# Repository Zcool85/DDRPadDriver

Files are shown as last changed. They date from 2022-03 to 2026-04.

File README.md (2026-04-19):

# Introduction

Projet de création d'un tapis de dance pour le jeu Dance Dance Revolution.

Ce tapis est utilisable sur un PC pour des jeux comme `Stepmania` ou `Outfox`, mais également sur
console Playstation (1 et 2).

Le firmware est à base de microcontroller AVR ©.

Les touches du tapis peuvent être illuminées. Dans ce cas, il convient d'ajouter une alimentation externe pour les LED (CAO `Power_Supply`). Cette alimentation est inutile si le tapis est utilisé sans éclairage.

## Licence

Le présent projet est sous licence MIT (Cf. [License](LICENSE.md)).

ATTENTION : Le Firmware utilise une librairie tierce V-USB pour la connexion USB vers un PC.
Cette librairie est soumie à une licnece GNU General Public License Version 2 (GPL). Merci
de consulter a license de cette bibliothèque en cas de modification.

Cf. [Librairie V-USB](https://obdev.at/products/vusb/index.html).

## Organisation du repo

Le répertoire `CAD` contient les fichiers de CAO des diférents composants :
- `Power_Supply` : Fichier CAO utilisé pour le bloc d'alimentation des tapis
- `For_Childrens` : Fichier CAO utilisé pour créer un tapis à la taille d'un enfant (~6ans)
- `For_Adults` : Fichier CAO utilisé pour créer un tapis pour adulte
- `Fonts` : Répertoire contenant les fonts utilisées par les fichiers de CAO

Le répertoire `Schematics` contient le shéma du circuit électronique du tapis.

Le répertoire `Datasheets` contient tous les datasheets des composants utilisés par le circuit électronique.

Le répertoire `Firmware` contient le code complet du firmware du microcontroller présent dans le circtui électronique.

Le répertoire `Documentation` Contient un peu de documentation permettant de comprendre comment fonctionne les trames d'une manette PS2.

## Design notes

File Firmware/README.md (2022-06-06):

# Introduction

Firmware pour un microcontoller AVR © permettant de gérer un tapis de dance DDR.

Ce firmware permet de se branche en USB sur un PC, ou sur une console Playstation.

## Trucs et astuces

### Installation des toolkit AVR GCC

Cf. [Doc](https://github.com/osx-cross/homebrew-avr)

```sh
brew tap osx-cross/avr
brew install avr-gcc
```

### Programmer les fuses

Commande à lancer (via ll'usage d'un AVR ISP mk II) :

```sh
avrdude -C avrdude.conf -p m324p -P usb -c avrispmkII -U efuse:w:efuse.bin:r -U hfuse:w:hfuse.bin:r -U lfuse:w:lfuse.bin:r
avrdude -C avrdude.conf -p m324p -P usb -c stk600pp   -U efuse:w:efuse.bin:r -U hfuse:w:hfuse.bin:r -U lfuse:w:lfuse.bin:r
```

### Faire une réinitialisation d'un AVR via Parallel High-Voltage Programming

Le présent process est fonctionnel pour une carte de développement STK600.

Cf. [Documentation](http://ww1.microchip.com/downloads/en/devicedoc/40001904a.pdf)

#### Pour un ATtiny48-PU

Use STK600-RC028M-6 PCB
Use STK600-DIP PCB

Connect PROGCTRL cable
Connect PROGDATA cable

Mount VTARGET jumper
Mount RESET jumper

avrdude -C avrdude.conf -c stk600pp -p attiny48 -P usb -U lfuse:w:lfuse.bin:r -U hfuse:w:hfuse.bin:r -U efuse:w:efuse.bin:r

#### Pour un ATMega324p-20PU

Use STK600-RC040M-5 PCB
Use STK600-DIP PCB

Connect PROGCTRL cable
Connect PROGDATA cable

Mount VTARGET jumper
Mount RESET jumper

avrdude -C avrdude.conf -c stk600pp -p m324p -P usb -U lfuse:w:lfuse.bin:r -U hfuse:w:hfuse.bin:r -U efuse:w:efuse.bin:r

### Visualiser les données USART sous MacOS

```sh
sudo cu -s 115200 -l /dev/tty.usbserial-A9IM6MKT
```

NOTE : `~.` pour terminer la communication.

### Visualiser la liste des périphérique USB sur MacOS

```sh
ioreg -p IOUSB
```

### Tester un joystick sous Windows

```cmd
joy.cpl
```

Note sur les [pilotes Windows](https://www.raphnet-tech.com/support/testing/index_fr.php).

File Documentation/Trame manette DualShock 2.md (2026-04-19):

# Trame Duacl Shock 2 sur PS2

Passage du mode digital à analogique (via la manette)

```
0x01/0xFF 0x42/0x41 0x00/0x5A 0x00/0xFF 0x00/0xFF
0x01/0xFF 0x42/0x41 0x00/0x5A 0x00/0xFF 0x00/0xFF
0x01/0xFF 0x42/0x41 0x00/0x5A 0x00/0xFF 0x00/0xFF
0x01/0xFF 0x42/0x41 0x00/0x5A 0x00/0xFF 0x00/0xFF
0x01/0xFF 0x42/0x41 0x00/0x5A 0x00/0xFF 0x00/0xFF
0x01/0xFF 0x42/0x41 0x00/0x5A 0x00/0xFF 0x00/0xFF
0x01/0xFF 0x42/0x41 0x00/0x5A 0x00/0xFF 0x00/0xFF
0x01/0xFF 0x42/0x41 0x00/0x5A 0x00/0xFF 0x00/0xFF
0x01/0xFF 0x42/0x41 0x00/0x5A 0x00/0xFF 0x00/0xFF
0x01/0xFF 0x42/0x41 0x00/0x5A 0x00/0xFF 0x00/0xFF
0x01/0xFF 0x42/0x41 0x00/0x5A 0x00/0xFF 0x00/0xFF
0x01/0xFF 0x42/0x41 0x00/0x5A 0x00/0xFF 0x00/0xFF
0x01/0xFF 0x42/0x41 0x00/0x5A 0x00/0xFF 0x00/0xFF
0x01/0xFF 0x42/0x73 0x00/0x00 0x00/0xFF 0x00/0xFF
0x01/0xFF 0x42/0x73 0x00/0x00 0x00/0xFF 0x00/0xFF
0x01/0xFF 0x43/0x73 0x00/0x00 0x01/0xFF 0x00/0xFF 0x00/0x79 0x00/0x89 0x00/0x75 0x00/0x71
0x01/0xFF 0x45/0xF3 0x00/0x5A 0x5A/0x03 0x5A/0x02 0x5A/0x01 0x5A/0x02 0x5A/0x01 0x5A/0x00
0x01/0xFF 0x46/0xF3 0x00/0x5A 0x00/0x00 0x5A/0x00 0x5A/0x01 0x5A/0x02 0x5A/0x00 0x5A/0x0A
0x01/0xFF 0x46/0xF3 0x00/0x5A 0x01/0x00 0x5A/0x00 0x5A/0x01 0x5A/0x01 0x5A/0x01 0x5A/0x14
0x01/0xFF 0x47/0xF3 0x00/0x5A 0x00/0x00 0x5A/0x00 0x5A/0x02 0x5A/0x00 0x5A/0x01 0x5A/0x00
0x01/0xFF 0x4C/0xF3 0x00/0x5A 0x00/0x00 0x5A/0x00 0x5A/0x00 0x5A/0x04 0x5A/0x00 0x5A/0x00
0x01/0xFF 0x4C/0xF3 0x00/0x5A 0x01/0x00 0x5A/0x00 0x5A/0x00 0x5A/0x07 0x5A/0x00 0x5A/0x00
0x01/0xFF 0x4D/0xF3 0x00/0x5A 0xFF/0xFF 0xFF/0xFF 0xFF/0xFF 0xFF/0xFF 0xFF/0xFF 0xFF/0xFF
0x01/0xFF 0x41/0xF3 0x00/0x5A 0x5A/0xFF 0x5A/0xFF 0x5A/0x03 0x5A/0x00 0x5A/0x00 0x5A/0x5A
0x01/0xFF 0x43/0xF3 0x00/0x5A 0x00/0x00 0x5A/0x00 0x5A/0x00 0x5A/0x00 0x5A/0x00 0x5A/0x00
0x01/0xFF 0x42/0x73 0x00/0x5A 0x00/0xFF 0x00/0xFF
0x01/0xFF 0x42/0x73 0x00/0x5A 0x00/0xFF 0x00/0xFF 0x00/0x79 0x00/0x89 0x00/0x75 0x00/0x71
0x01/0xFF 0x42/0x73 0x00/0x5A 0x00/0xFF 0x00/0xFF 0x00/0x79 0x00/0x89 0x00/0x75 0x00/0x71
0x01/0xFF 0x42/0x73 0x00/0x5A 0x00/0xFF 0x00/0xFF 0x00/0x79 0x00/0x89 0x00/0x75 0x00/0x71
0x01/0xFF 0x42/0x73 0x00/0x5A 0x00/0xFF 0x00/0xFF 0x00/0x79 0x00/0x89 0x00/0x75 0x00/0x71
0x01/0xFF 0x42/0x73 0x00/0x5A 0x00/0xFF 0x00/0xFF 0x00/0x79 0x00/0x89 0x00/0x75 0x00/0x71
0x01/0xFF 0x42/0x73 0x00/0x5A 0x00/0xFF 0x00/0xFF 0x00/0x79 0x00/0x89 0x00/0x75 0x00/0x71
0x01/0xFF 0x42/0x73 0x00/0x5A 0x00/0xFF 0x00/0xFF 0x00/0x79 0x00/0x89 0x00/0x75 0x00/0x71
0x01/0xFF 0x42/0x73 0x00/0x5A 0x00/0xFF 0x00/0xFF 0x00/0x79 0x00/0x89 0x00/0x75 0x00/0x71
0x01/0xFF 0x42/0x73 0x00/0x5A 0x00/0xFF 0x00/0xFF 0x00/0x79 0x00/0x89 0x00/0x75 0x00/0x71
0x01/0xFF 0x42/0x73 0x00/0x5A 0x00/0xFF 0x00/0xFF 0x00/0x79 0x00/0x89 0x00/0x75 0x00/0x71
0x01/0xFF 0x42/0x73 0x00/0x5A 0x00/0xFF 0x00/0xFF 0x00/0x79 0x00/0x89 0x00/0x75 0x00/0x71
0x01/0xFF 0x42/0x73 0x00/0x5A 0x00/0xFF 0x00/0xFF 0x00/0x79 0x00/0x89 0x00/0x75 0x00/0x71
0x01/0xFF 0x42/0x73 0x00/0x5A 0x00/0xFF 0x00/0xFF 0x00/0x79 0x00/0x89 0x00/0x75 0x00/0x71
0x01/0xFF 0x42/0x73 0x00/0x5A 0x00/0xFF 0x00/0xFF 0x00/0x79 0x00/0x89 0x00/0x75 0x00/0x71
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
```

NOTE : Une trame complète toutes les 20ms environ.

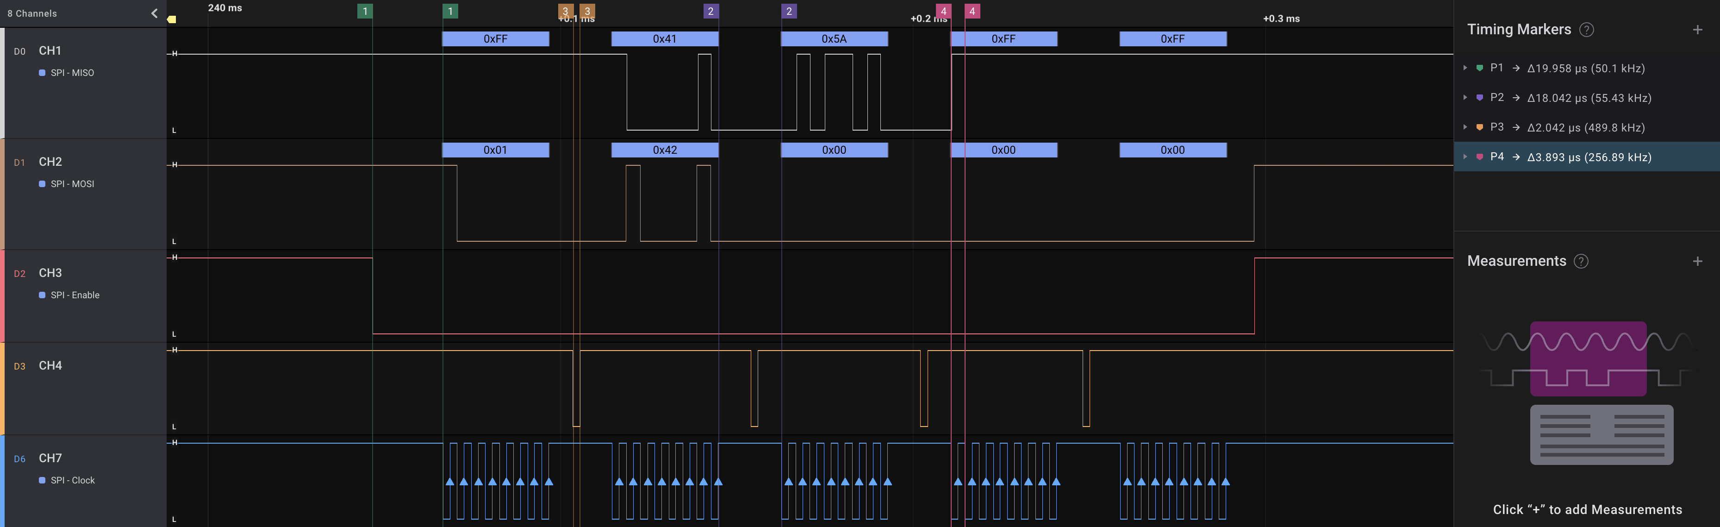
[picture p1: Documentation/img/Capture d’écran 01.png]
Trame 1

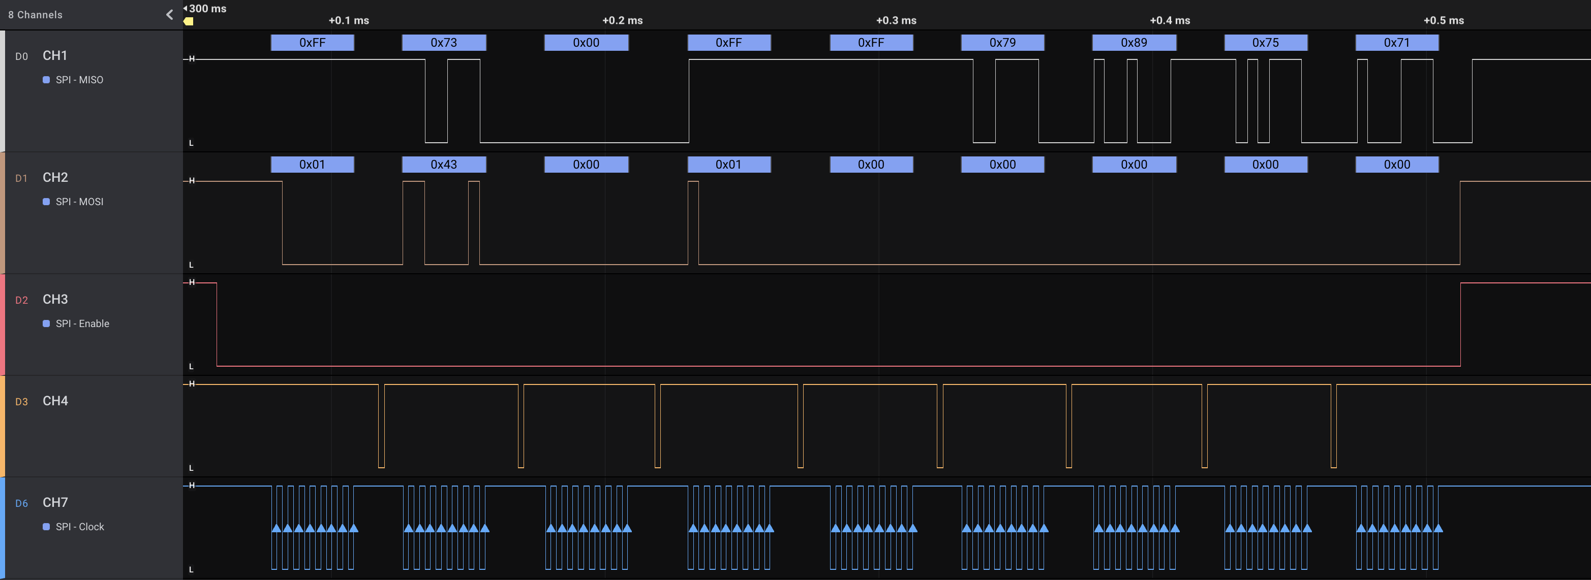
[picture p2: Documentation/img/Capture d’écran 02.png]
Trame 2

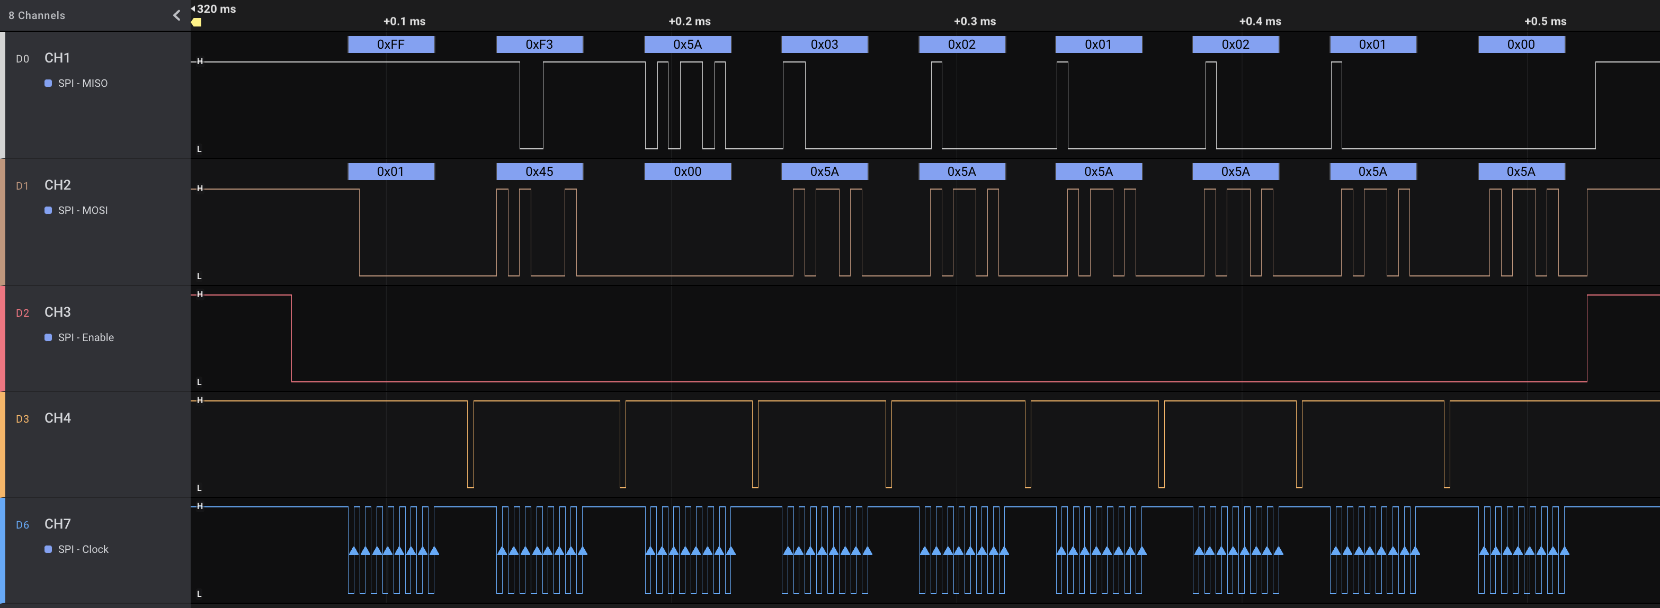
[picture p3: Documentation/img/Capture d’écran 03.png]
Trame 3

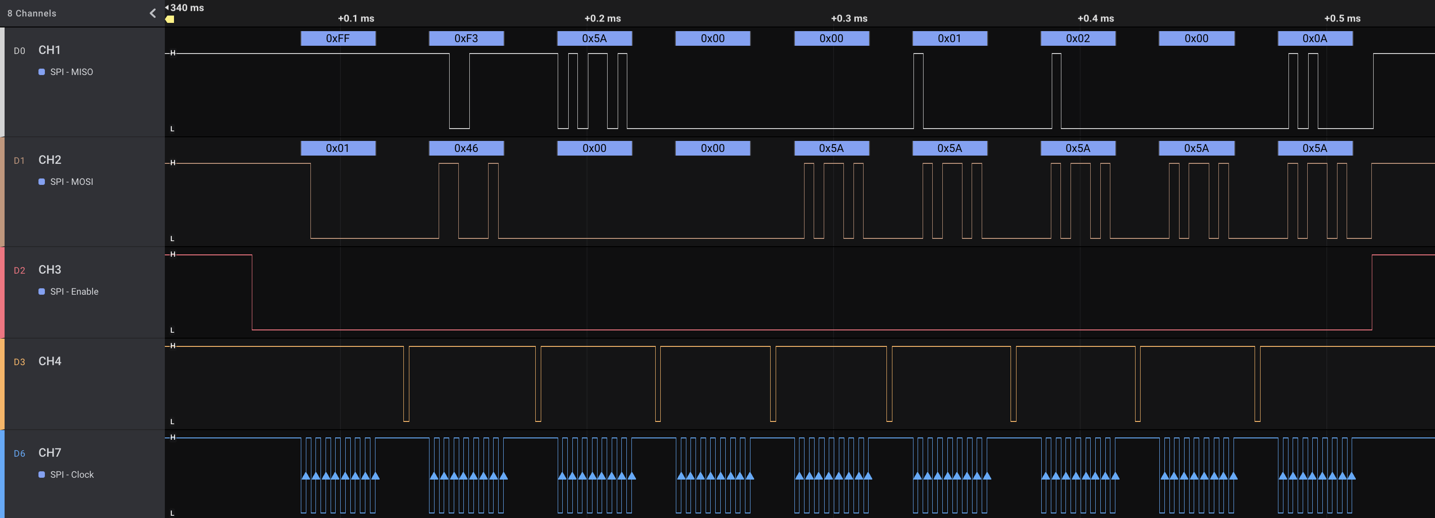
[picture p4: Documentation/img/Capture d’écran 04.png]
Trame 4

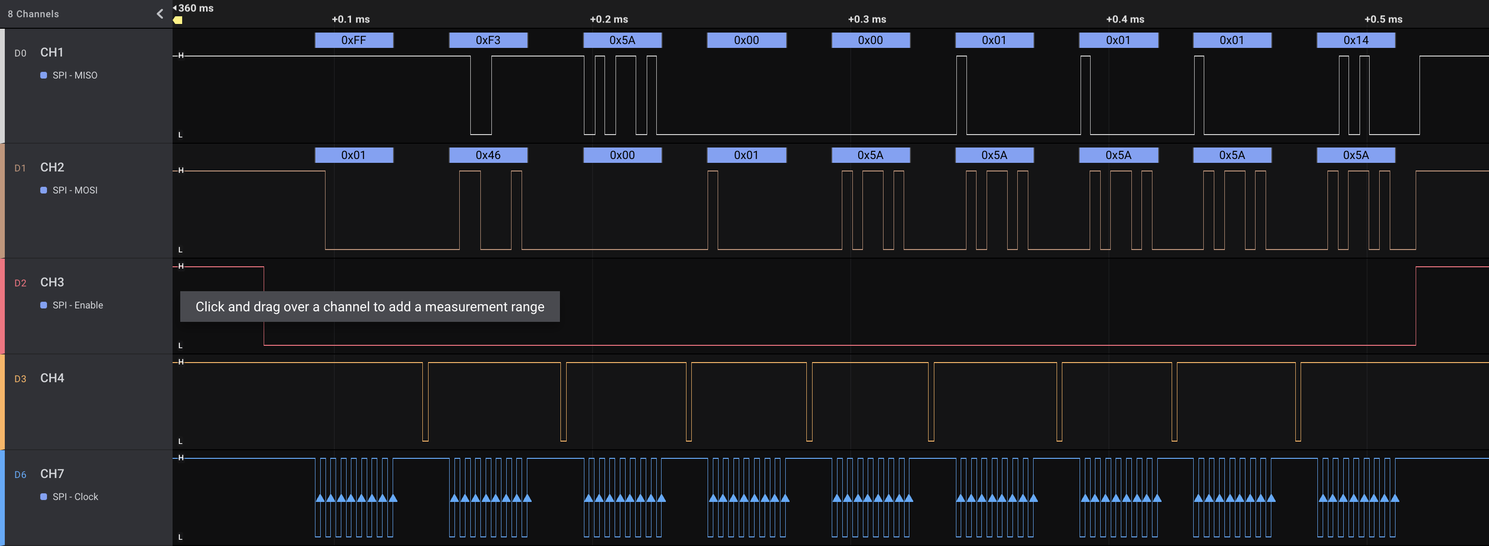
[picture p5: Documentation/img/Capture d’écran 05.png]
Trame 5

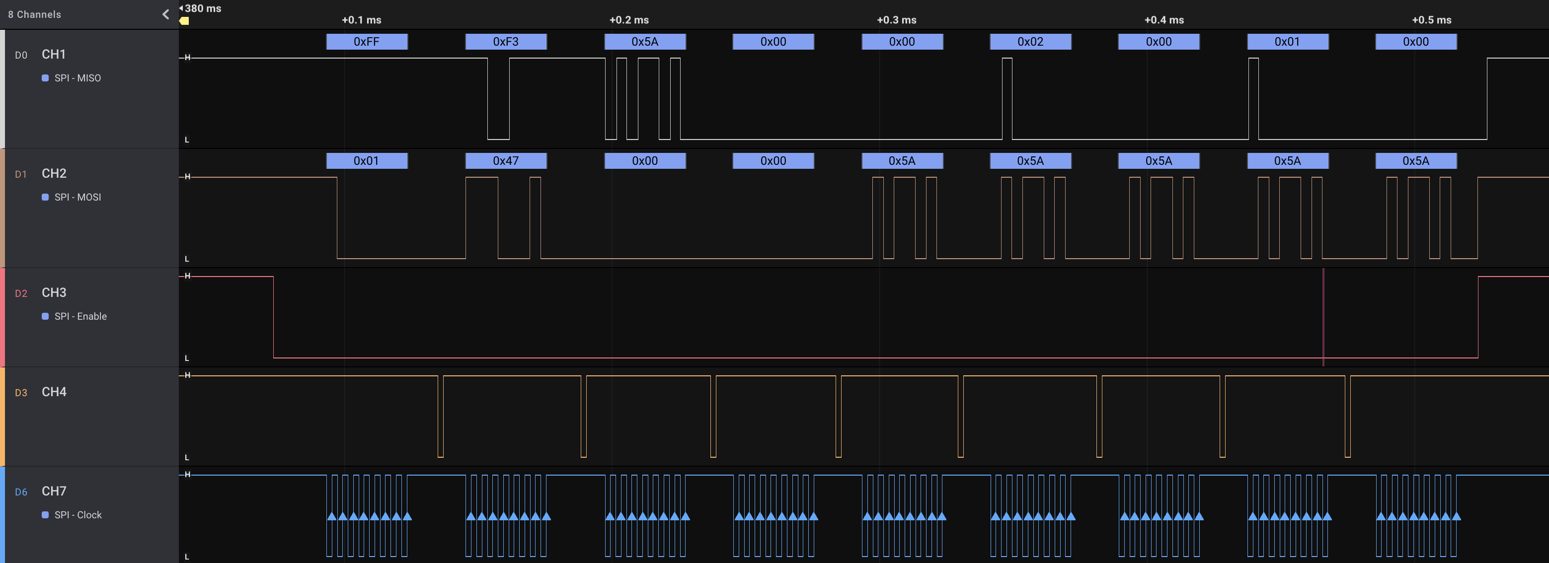
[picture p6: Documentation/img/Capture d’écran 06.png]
Trame 6

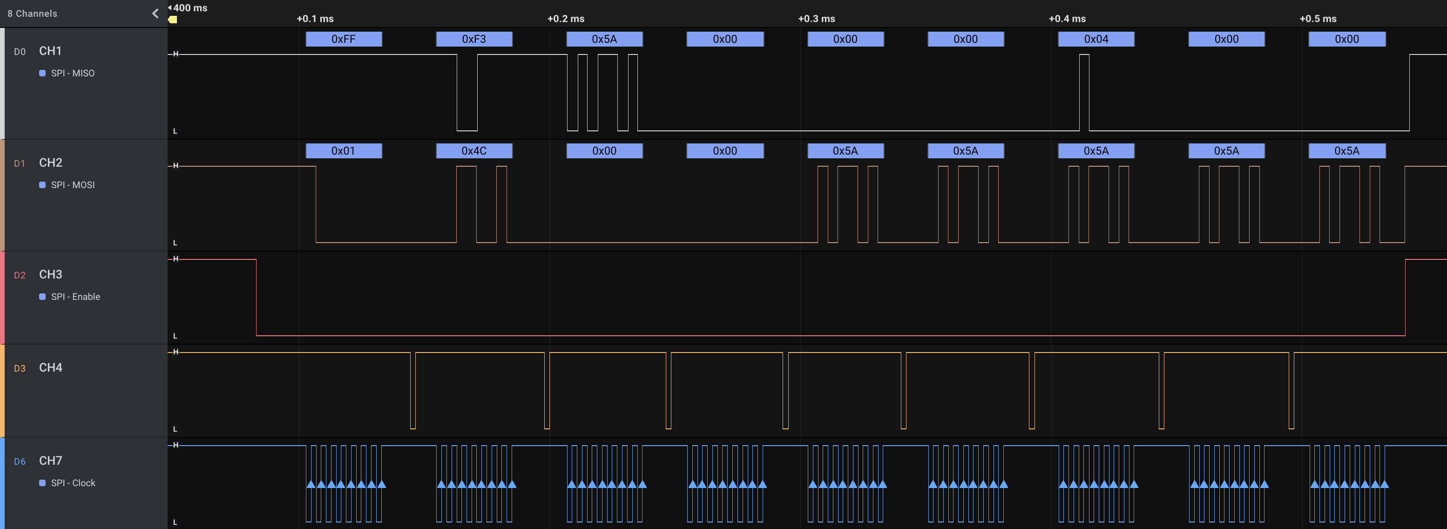
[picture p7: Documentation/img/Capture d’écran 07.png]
Trame 7

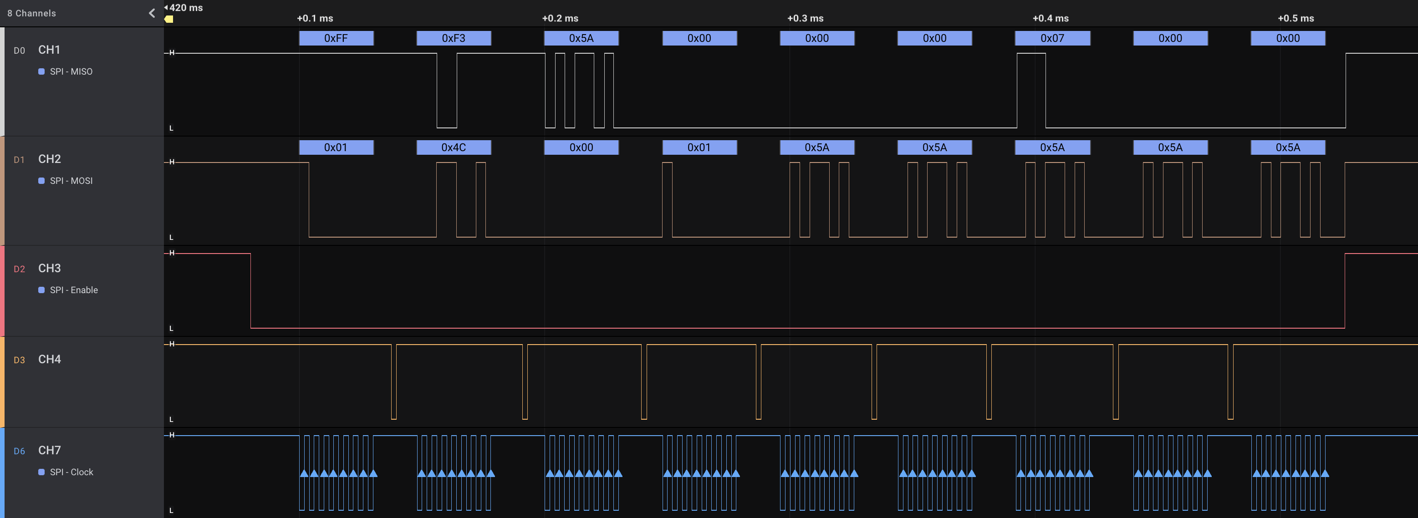
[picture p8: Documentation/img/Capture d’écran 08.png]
Trame 8

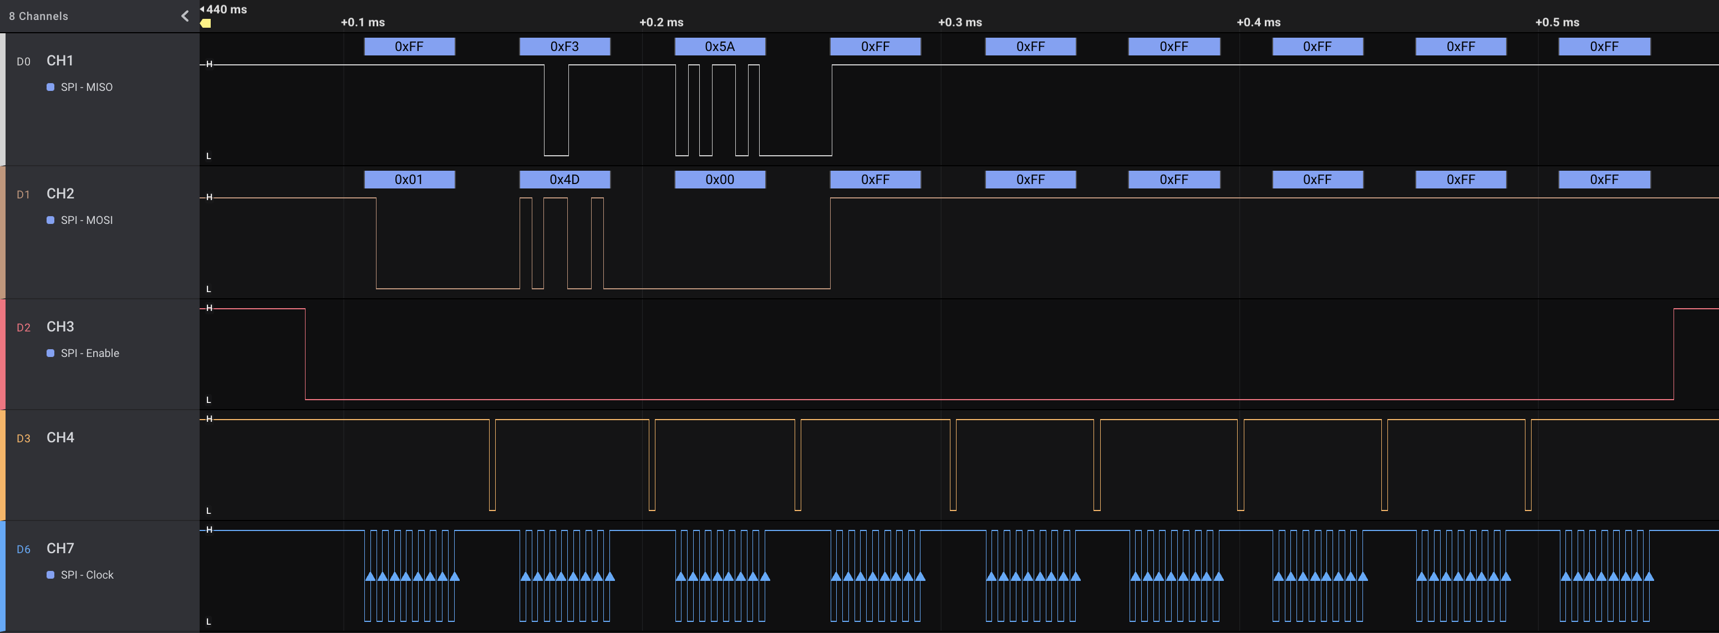
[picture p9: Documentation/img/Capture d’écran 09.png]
Trame 9

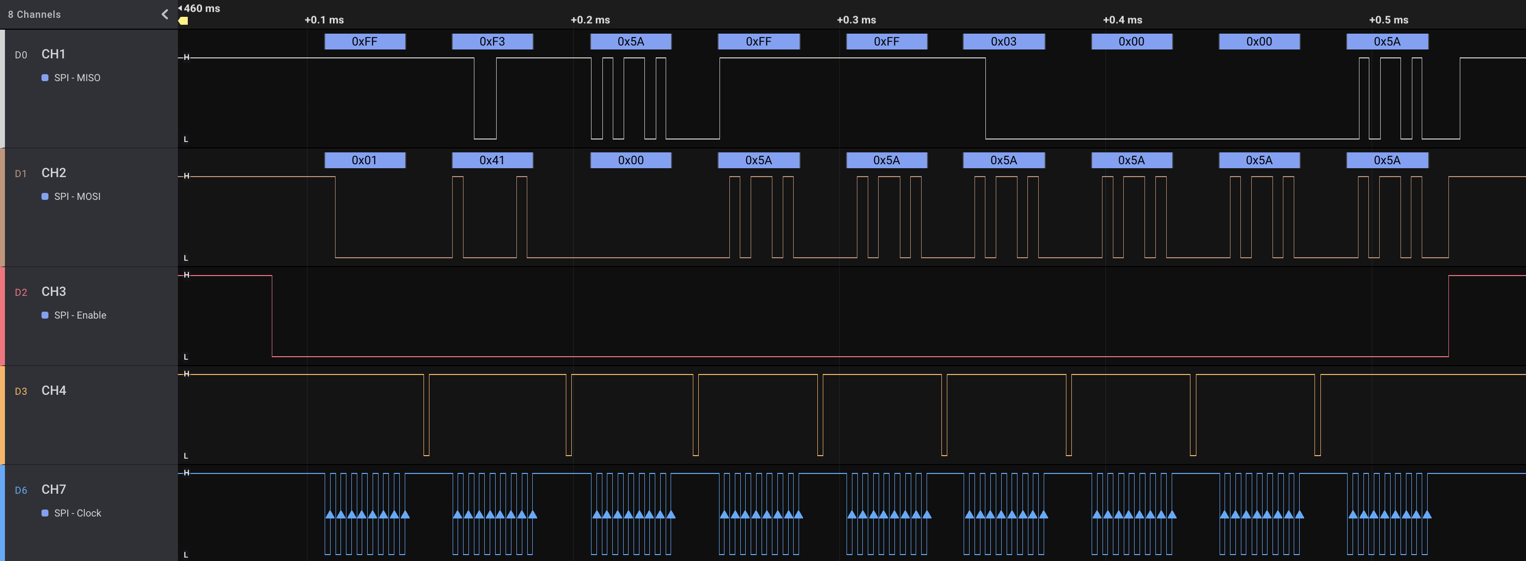
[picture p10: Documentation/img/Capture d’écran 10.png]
Trame 10

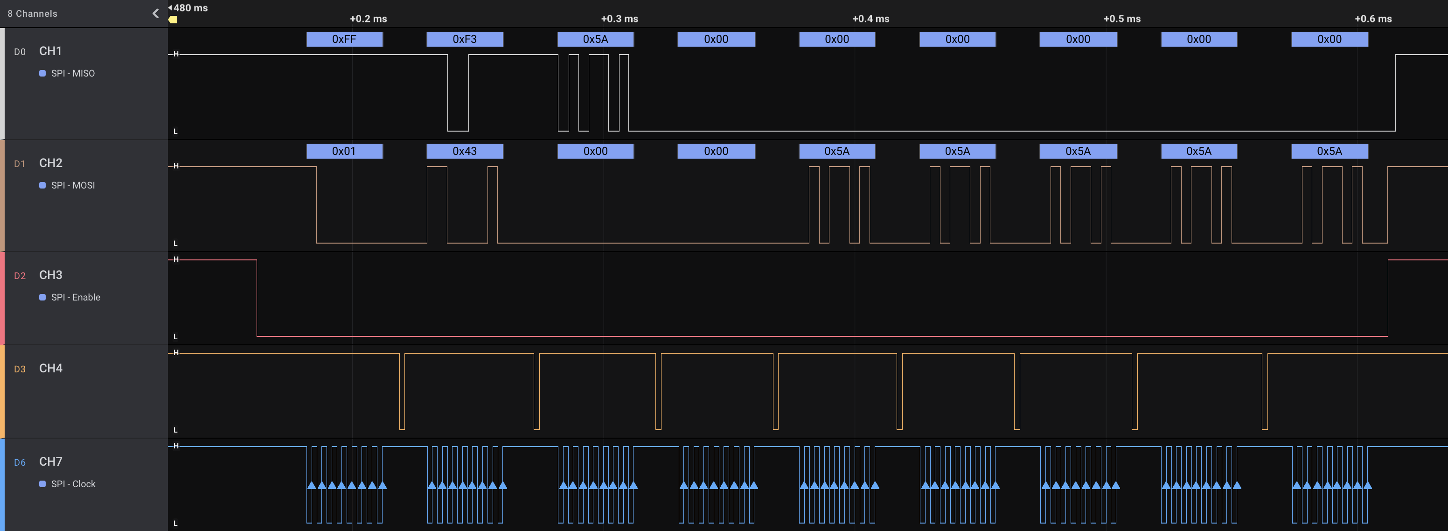
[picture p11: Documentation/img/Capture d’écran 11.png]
Trame 11

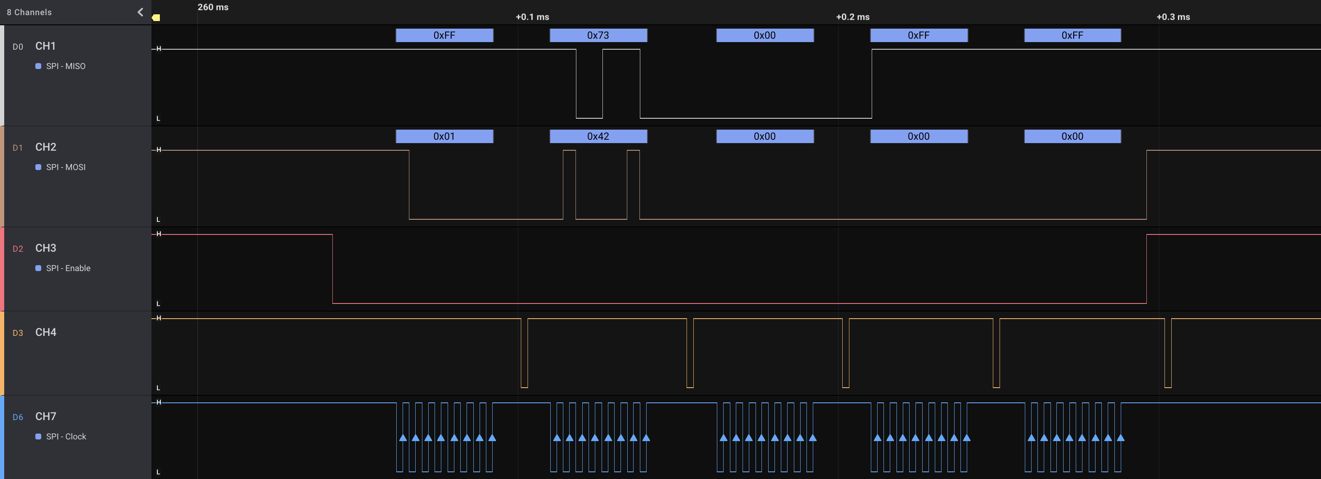
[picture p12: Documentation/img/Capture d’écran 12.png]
Trame 12

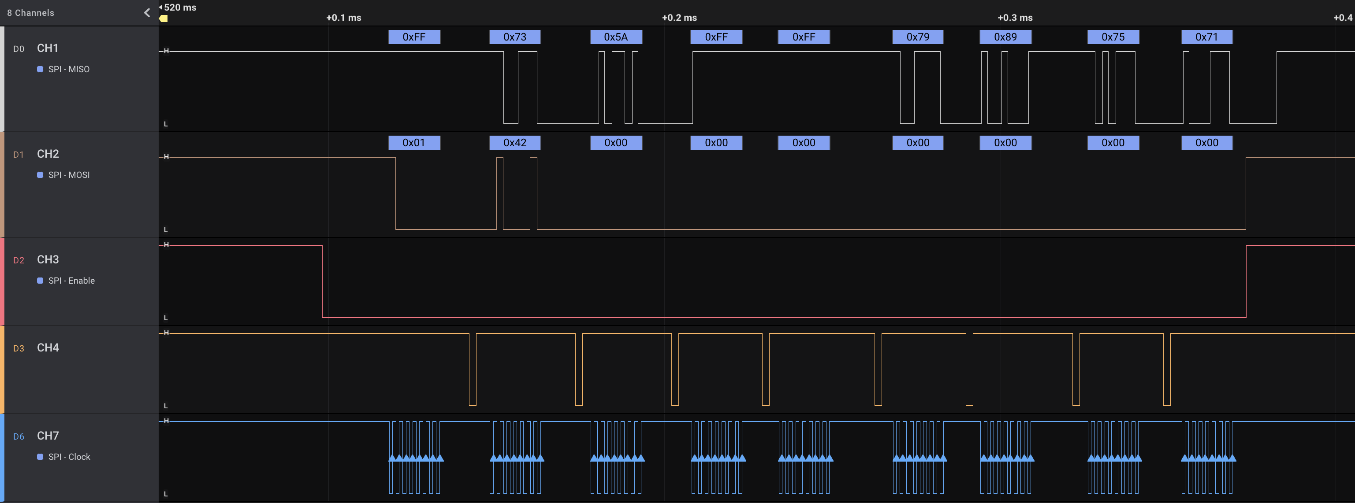
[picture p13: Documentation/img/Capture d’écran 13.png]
Trame 13


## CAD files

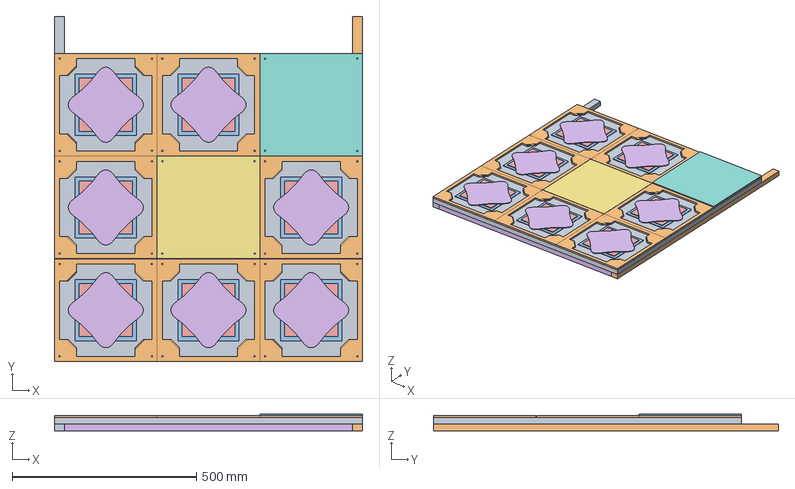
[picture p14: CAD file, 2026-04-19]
CAD/For_Adults/DancePad.FCStd
835.0 x 935.0 x 45.0 mm
Border_Body x 8
ContactBottom_Body x 16
ContactIsolation_Body x 8
FirstPadding_Body x 8
SecondPadding_Body x 8
VerticalSupport_Right_Body
VerticalSupport_Left_Body
HorizontalCrossing_Left_Body
HorizontalCrossing_Right_Body
HorizontalSupport_Up_Body
HorizontalSupport_Bottom_Body
VerticalCrossing_Body

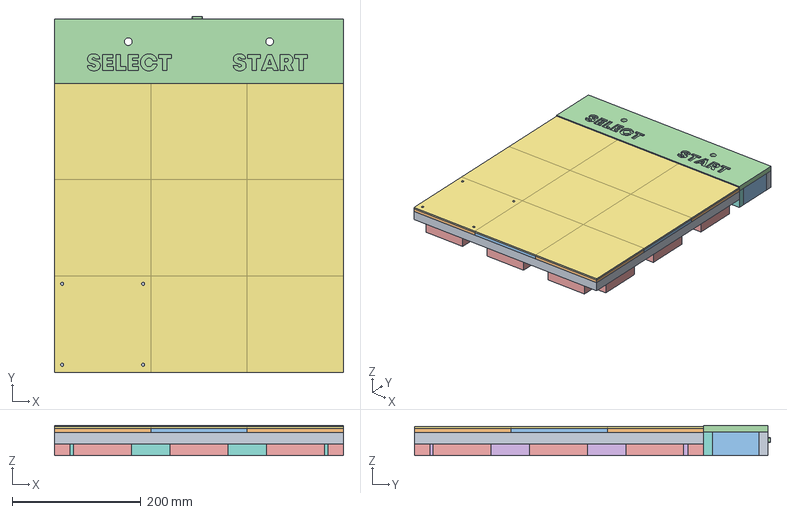
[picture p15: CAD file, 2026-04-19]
CAD/For_Childrens/LittleDancePad.FCStd
450.0 x 554.0 x 47.0 mm
Border_Body x 4
ContactBase_Body x 4
BottomContact_Body x 8
Isolation_Body x 4
Panel_Body
Pcb_1623
Y1_Crystal_HC49-U_Vertical_626D12A7
U3_SOIC_16_39x99mm_P127mm_626D11E8
R65_R_0805_2012Metric_626D1172 x 65
L1_L_2816_7142Metric_626D0C5E
J29_DSUB-9_Female_Horizontal_P2.77x2.84mm_EdgePinOffset7.70mm_Housed_ MountingHolesOffset9.12mm_626D0C4D
D22_D_SOT_23_626D0966 x 18
D1_D_SMA_626D0759
C6_C_0805_2012Metric_626D0741 x 6
U10_SMDIP_4_W953mm_626D1290 x 8
U1_DIP-40_W15.24mm_626E0E3D
Q9_SOT_223_626D0D21 x 8
J10_PinHeader_2x04_P254mm_Horizontal_626D0C19 x 6
J4_PinHeader_1x03_P254mm_Vertical_626E050C
J2_IDC_Header_2x03_P254mm_Vertical_626D09CF
D6_LED_0603_1608Metric_Castellated_626D07C6 x 3

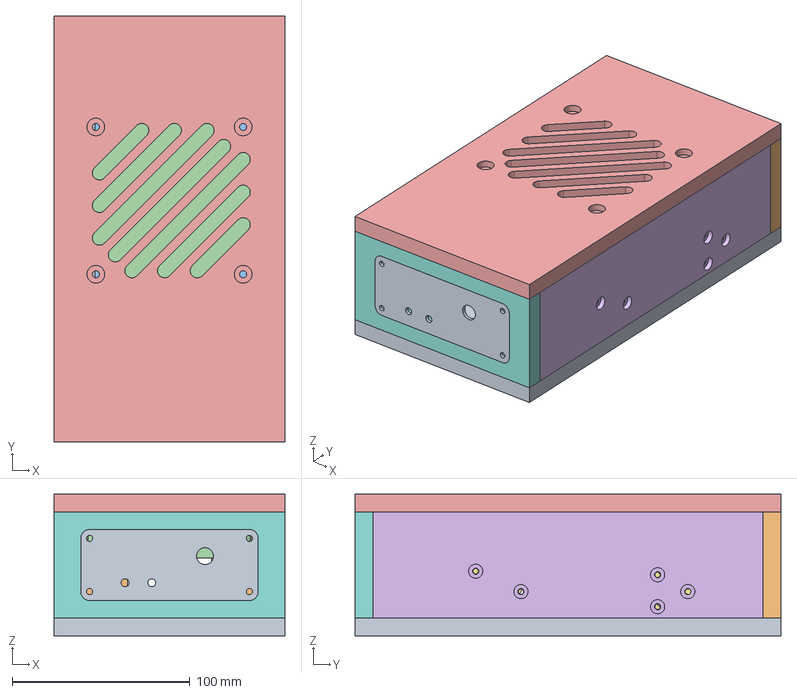
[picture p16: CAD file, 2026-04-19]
CAD/Power_Supply/Power_Supply.FCStd
130.0 x 240.0 x 80.0 mm
Bottom_Body
Back_Body
BottomPart_Body
Fan_Body
Top_Body
Left_Body
Front_Body
AluminiumProfile_Body

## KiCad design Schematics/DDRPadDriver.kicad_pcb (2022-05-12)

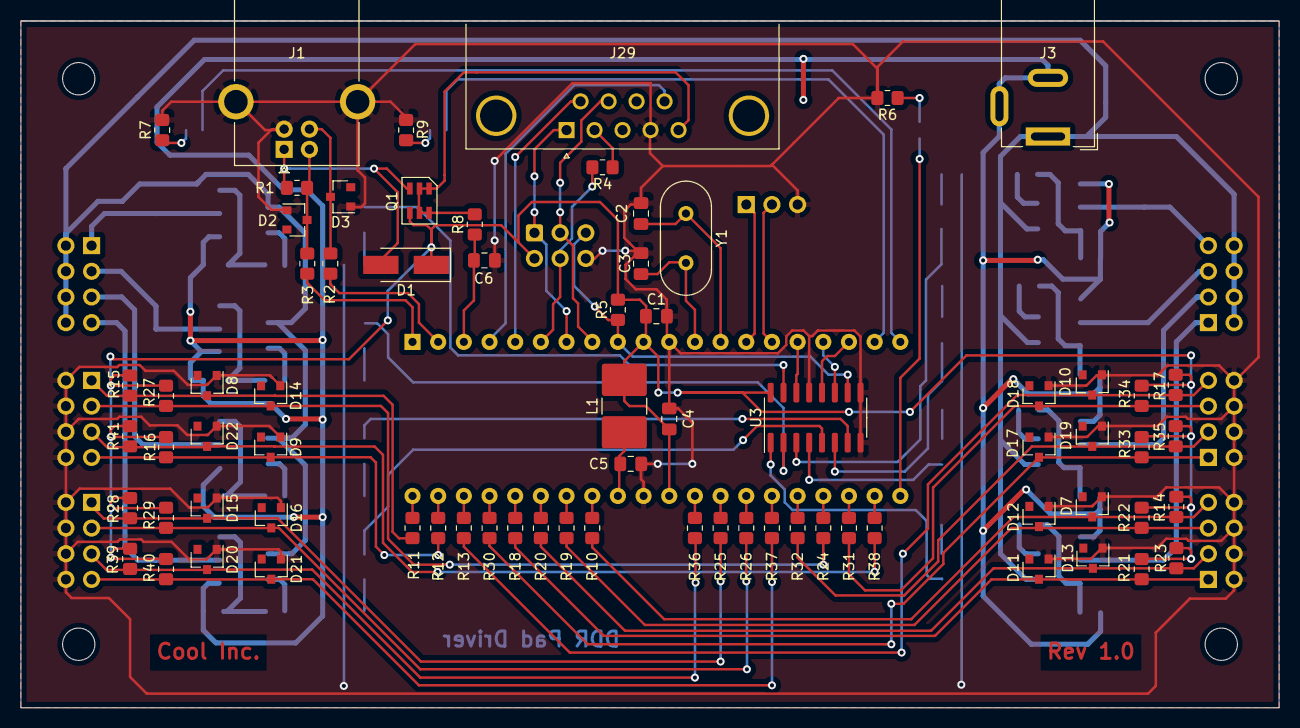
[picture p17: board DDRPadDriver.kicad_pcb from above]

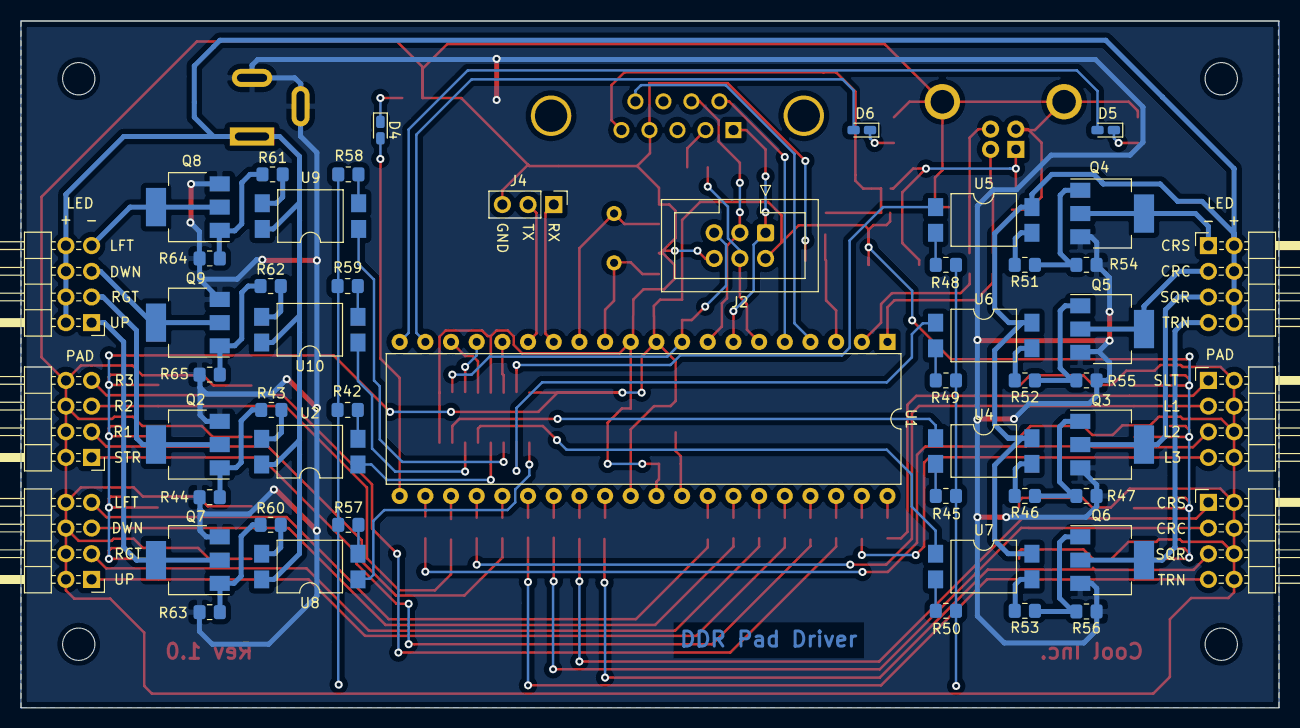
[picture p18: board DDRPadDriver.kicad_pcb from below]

Board: 2 copper layers, 124.5 x 67.9 mm, 129 parts (52 on the bottom side), 104 nets.

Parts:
C1: 4.7uF; C_0805_2012Metric_Pad1.18x1.45mm_HandSolder
C2, C3: 10pF; C_0805_2012Metric_Pad1.18x1.45mm_HandSolder
C4, C5, C6: 0.1uF; C_0805_2012Metric_Pad1.18x1.45mm_HandSolder
D1: SS12; D_SMA_Handsoldering
D2, D3: 3V6; D_SOT-23_ANK
D4, D5, D6: LED; LED_0603_1608Metric_Castellated
D7, D8, D9, D10, D11, D12, D13, D14, D15, D16, D17, D18, D19, D20, D21, D22: BZX84C3V6; D_SOT-23_ANK
H1, H2, H3, H4: MountingHole; MountingHole_3.2mm_M3
J1: USB_B; USB_B_OST_USB-B1HSxx_Horizontal
J2: AVR-ISP-6; IDC-Header_2x03_P2.54mm_Vertical
J3: Barrel_Jack_Switch; BarrelJack_Wuerth_6941xx301002
J4: Conn_01x03_Male; PinHeader_1x03_P2.54mm_Vertical
J5, J6, J7, J8, J9, J10: Conn_01x08_Male; PinHeader_2x04_P2.54mm_Horizontal
J29: PS2; DSUB-9_Female_Horizontal_P2.77x2.84mm_EdgePinOffset7.70mm_H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
L1: 10mH; L_2816_7142Metric_Pad3.20x4.45mm_HandSolder
Q1: PMN30XPA; TSOP-6_3pins
Q2, Q3, Q4, Q5, Q6, Q7, Q8, Q9: BCP56; SOT-223-3_TabPin2
R1: 1K5; R_0805_2012Metric_Pad1.20x1.40mm_HandSolder
R2, R3: 68; R_0805_2012Metric_Pad1.20x1.40mm_HandSolder
R4, R5, R8: 10K; R_0805_2012Metric_Pad1.20x1.40mm_HandSolder
R6, R7, R9, R10, R11, R12, R13, R18, R19, R20, R24, R25, R26, R30, R31, R32, R36, R37, R38, R42, R45, R48, R49, R50, R57, R58, R59: 470; R_0805_2012Metric_Pad1.20x1.40mm_HandSolder
R14, R15, R16, R17, R21, R22, R23, R27, R28, R29, R33, R34, R35, R39, R40, R41: 680; R_0805_2012Metric_Pad1.20x1.40mm_HandSolder
R43, R46, R51, R52, R53, R60, R61, R62: 1K; R_0805_2012Metric_Pad1.20x1.40mm_HandSolder
R44, R47, R54, R55, R56, R63, R64, R65: 4K7; R_0805_2012Metric_Pad1.20x1.40mm_HandSolder
U1: ATmega164P-20PU; DIP-40_W15.24mm
U2, U4, U5, U6, U7, U8, U9, U10: SFH620A-2X007T; SMDIP-4_W9.53mm_Clearance8mm
U3: 74HC595; SOIC-16_3.9x9.9mm_P1.27mm
Y1: 12MHz; Crystal_HC49-U_Vertical

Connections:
3V3: J29.5, Q1.3, R8.2
5V: D1.2, J1.1, Q1.1, R1.1
12V: J3.1, J9.2, J9.4, J9.6, J9.8, J10.2, J10.4, J10.6, J10.8, U2.4, U4.4, U5.4, U6.4, U7.4, U8.4, U9.4, U10.4
/B1-CROSS: R25.2, U1.28
/B2-CIRCLE: R26.2, U1.27
/B3-SQUARE: R36.2, U1.29
/B4-TRIANGLE: R37.2, U1.26
/D+: R2.2, U1.2
/D-: R3.2, U1.1
/DOWN: R19.2, U1.34
/L1: R24.2, U1.24
/L2: R38.2, U1.22
/L3: R12.2, U1.39
/LEDs/L-CIRCLE: J10.3, Q5.2
/LEDs/L-CROSS: J10.1, Q4.2
/LEDs/L-DOWN: J9.5, Q9.2
/LEDs/L-LEFT: J9.7, Q8.2
/LEDs/L-RIGHT: J9.3, Q2.2
/LEDs/L-SQUARE: J10.5, Q3.2
/LEDs/L-TRIANGLE: J10.7, Q6.2
/LEDs/L-UP: J9.1, Q7.2
/LEDs/LED-B: U3.6, U10.1
/LEDs/LED-BL: U3.5, U7.1
/LEDs/LED-BR: U3.7, U4.1
/LEDs/LED-L: U3.3, U9.1
/LEDs/LED-R: U2.1, U3.4
/LEDs/LED-U: U3.1, U8.1
/LEDs/LED-UL: U3.15, U5.1
/LEDs/LED-UR: U3.2, U6.1
/LEFT: R10.2, U1.33
/MISO: J2.1, J29.1, U1.7
/MOSI: J2.4, R4.2, U1.6
/PSX_DSR: J29.9, U1.4
/PSX_SCK: J2.3, J29.7, U1.8
/PSX_TXD: J29.2, R4.1
/Pads/C_CIRCLE: D16.1, J6.3, R26.1, R29.2
/Pads/C_CROSS: D15.1, J6.1, R25.1, R28.2
/Pads/C_DOWN: D12.1, J5.5, R19.1, R22.2
/Pads/C_L1: D14.1, J8.3, R24.1, R27.2
/Pads/C_L2: D22.1, J8.5, R38.1, R41.2
/Pads/C_L3: D9.1, J8.7, R12.1, R16.2
/Pads/C_LEFT: D7.1, J5.7, R10.1, R14.2
/Pads/C_R1: D19.1, J7.3, R32.1, R35.2
/Pads/C_R2: D18.1, J7.5, R31.1, R34.2
/Pads/C_R3: D10.1, J7.7, R13.1, R17.2
/Pads/C_RIGHT: D13.1, J5.3, R20.1, R23.2
/Pads/C_SELECT: D8.1, J8.1, R11.1, R15.2
/Pads/C_SQUARE: D20.1, J6.5, R36.1, R39.2
/Pads/C_START: D17.1, J7.1, R30.1, R33.2
/Pads/C_TRIANGLE: D21.1, J6.7, R37.1, R40.2
/Pads/C_UP: D11.1, J5.1, R18.1, R21.2
/R1: R32.2, U1.25
/R2: R31.2, U1.23
/R3: R13.2, U1.38
/RIGHT: R20.2, U1.35
/RX: J4.1, U1.14
/S1-SELECT: R11.2, U1.40
/S2-START: R30.2, U1.37
/SHIFT_CLK: U1.17, U3.11
/SHIFT_RCK: U1.18, U3.12
/SHIFT_SER: U1.16, U3.14
/TX: J4.2, U1.15
/UP: R18.2, U1.36
/~PSX_DTR~: J29.6, U1.5
/~RESET~: J2.5, R5.2, U1.9, U3.10
GND: C1.2, C2.1, C3.1, C4.2, C5.2, C6.2, D2.2, D3.2, D7.2, D8.2, D9.2, D10.2, D11.2, D12.2, D13.2, D14.2, D15.2, D16.2, D17.2, D18.2, D19.2, D20.2, D21.2, D22.2, J1.4, J1.5, J2.6, J4.3, J5.2, J5.4, J5.6, J5.8, J6.2, J6.4, J6.6, J6.8, J7.2, J7.4, J7.6, J7.8, J8.2, J8.4, J8.6, J8.8, J29.4, R6.2, R7.2, R9.2, R42.2, R45.2, R48.2, R49.2, R50.2, R57.2, R58.2, R59.2, U1.11, U1.31, U3.8, U3.9, U3.13
GND12V: J3.2, J3.3, Q2.3, Q3.3, Q4.3, Q5.3, Q6.3, Q7.3, Q8.3, Q9.3, R44.1, R47.1, R54.1, R55.1, R56.1, R63.1, R64.1, R65.1
unnamed: C2.2, U1.13, Y1.1
unnamed: C3.2, U1.12, Y1.2
unnamed: C5.1, L1.2, U1.32
unnamed: C6.1, R8.1, U1.3
unnamed: D2.1, J1.2, R1.2, R3.1
unnamed: D3.1, J1.3, R2.1
unnamed: D4.1, R6.1
unnamed: D4.2, U1.21
unnamed: D5.1, R7.1
unnamed: D5.2, U1.20
unnamed: D6.1, R9.1
unnamed: D6.2, U1.19
unnamed: Q2.1, R43.1, R44.2
unnamed: Q3.1, R46.1, R47.2
unnamed: Q4.1, R51.1, R54.2
unnamed: Q5.1, R52.1, R55.2
unnamed: Q6.1, R53.1, R56.2
unnamed: Q7.1, R60.1, R63.2
unnamed: Q8.1, R61.1, R64.2
unnamed: Q9.1, R62.1, R65.2
unnamed: R42.1, U2.2
unnamed: R43.2, U2.3
unnamed: R45.1, U4.2
unnamed: R46.2, U4.3
unnamed: R48.1, U5.2
unnamed: R49.1, U6.2
unnamed: R50.1, U7.2
unnamed: R51.2, U5.3
unnamed: R52.2, U6.3
unnamed: R53.2, U7.3
unnamed: R57.1, U8.2
unnamed: R58.1, U9.2
unnamed: R59.1, U10.2
unnamed: R60.2, U8.3
unnamed: R61.2, U9.3
unnamed: R62.2, U10.3
VCC: C1.1, C4.1, D1.1, J2.2, L1.1, Q1.2, R5.1, R14.1, R15.1, R16.1, R17.1, R21.1, R22.1, R23.1, R27.1, R28.1, R29.1, R33.1, R34.1, R35.1, R39.1, R40.1, R41.1, U1.10, U1.30, U3.16

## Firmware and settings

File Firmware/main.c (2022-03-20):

/**
 * @file      main.c
 *
 * @author    Zéro Cool
 * @date      19/02/2022
 * @brief     Driver PAD DDR USB
 *
 * @details   Code source du programme driver PAD DDR PS2 à base de ATmega164p
 *
 * @copyright   Copyright © 2022 Zéro Cool
 */

//
//         ATmega164p / ATmega324p / ATmega644p
//

//                             ------U------
//    D- --------------- PB0 -| 1        40 |- PA0 <------------ S1-SELECT
//    D+ --------------- PB1 -| 2        39 |- PA1 <------------ L3
//    3V3 input -------> PB2 -| 3        38 |- PA2 <------------ R3
//    PSX_DSR <--Hi-Z--- PB3 -| 4        37 |- PA3 <------------ S2-START
//    PSX_DTR ---------> PB4 -| 5        36 |- PA4 <------------ UP
//    PSX_TXD ---------> PB5 -| 6        35 |- PA5 <------------ RIGHT
//    PSX_RXD <--Hi-Z--- PB6 -| 7        34 |- PA6 <------------ DOWN
//    PSX_SCK ---------> PB7 -| 8        33 |- PA7 <------------ LEFT
//                   _RESET_ -| 9        32 |- AREF
//                       VCC -| 10       31 |- GND
//                       GND -| 11       30 |- AVCC
//                     XTAL2 -| 12       29 |- PC7 <------------ B3-SUARE
//                     XTAL1 -| 13       28 |- PC6 <------------ B1-CROSS
//    RX --------------> PD0 -| 14       27 |- PC5 <------------ B2-CIRCLE
//    TX <-------------- PD1 -| 15       26 |- PC4 <------------ B4-TRIANGLE
//    SHIFT_SER <------- PD2 -| 16       25 |- PC3 <------------ R1
//    SHIFT_CLK <------- PD3 -| 17       24 |- PC2 <------------ L1
//    SHIFT_RCK <------- PD4 -| 18       23 |- PC1 <------------ R2
//    LED PSX <--------- PD5 -| 19       22 |- PC0 <------------ L2
//    LED USB <--------- PD6 -| 20       21 |- PD7 ------------> LED PAD
//                             -------------

// FUSES :
// -------

// ----- extented fuse
// Fuse      | Bit No | Description                                       | Default value                          | Desired Value
// ----------|--------|---------------------------------------------------|----------------------------------------|-------------------
//           | 7      |                                                   | 1 (unprogrammed)                       | 1
//           | 6      |                                                   | 1 (unprogrammed)                       | 1
//           | 5      |                                                   | 1 (unprogrammed)                       | 1
//           | 4      |                                                   | 1 (unprogrammed)                       | 1
//           | 3      |                                                   | 1 (unprogrammed)                       | 1
// BODLEVEL2 | 2      | Brown-out Detector trigger level                  | 1 (unprogrammed)                       | 1
// BODLEVEL1 | 1      | Brown-out Detector trigger level                  | 1 (unprogrammed)                       | 1
// BODLEVEL0 | 0      | Brown-out Detector trigger level                  | 1 (unprogrammed)                       | 1
// => efuse = 0xFF (default 0xFF)

// ----- high fuse
// Fuse      | Bit No | Description                                       | Default value                          | Desired Value
// ----------|--------|---------------------------------------------------|----------------------------------------|-------------------
// OCDEN     | 7      | Enable OCD                                        | 1 (unprogrammed, OCD disabled)         | 1
// JTAGEN    | 6      | Enable JTAG                                       | 0 (programmed, JTAG enabled)           | 1
// SPIEN     | 5      | Enable SPI Serial Program and Data Downloading    | 0 (programmed, SPI prog. enabled)      | 0
// WDTON     | 4      | Watchdog Timer always on                          | 1 (unprogrammed)                       | 1
// EESAVE    | 3      | EEPROM memory is preserved through the Chip Erase | 1 (unprogrammed, EEPROM not preserved) | 1
// BOOTSZ1   | 2      | Select Boot Size (see Table 99 for details)       | 0 (programmed)                         | 0
// BOOTSZ0   | 1      | Select Boot Size (see Table 99 for details)       | 0 (programmed)                         | 0
// BOOTRST   | 0      | Select reset vector                               | 1 (unprogrammed)                       | 1
// => hfuse = 0xD9 (default 0x99)

// ----- low fuse
// Fuse       | Bit No | Description                                       | Default value                          | Desired Value
// -----------|--------|---------------------------------------------------|----------------------------------------|-------------------
// CKDIV8     | 7      | Divide clock by 8                                 | 0 (programmed)                         | 1
// CKOUT      | 6      | Clock output                                      | 1 (unprogrammed)                       | 1
// SUT1       | 5      | Select start-up time                              | 1 (unprogrammed)                       | 1 (slowly rising power)
// SUT0       | 4      | Select start-up time                              | 0 (programmed)                         | 1
// CKSEL3     | 3      | Select Clock source                               | 0 (programmed)                         | 0 (Full Swing Crystal Oscillator)
// CKSEL2     | 2      | Select Clock source                               | 0 (programmed)                         | 1
// CKSEL1     | 1      | Select Clock source                               | 1 (unprogrammed)                       | 1
// CKSEL0     | 0      | Select Clock source                               | 0 (programmed)                         | 1
// => lfuse = 0xF7 (default 0x62)

/*
echo -n -e '\xFF' > efuse.bin
echo -n -e '\xD9' > hfuse.bin
echo -n -e '\xF7' > lfuse.bin
*/

/******************************************************************************
 * Standard libraries
 ******************************************************************************/

#include <avr/io.h>
#include <avr/interrupt.h>
#include <avr/power.h>
#include <avr/wdt.h>
#include <util/delay.h>
#include <stdio.h>


/******************************************************************************
 * Header files
 ******************************************************************************/

// Gestion de l'USART
#include "usart.h"

// HC595
#include "hc595.h"

// PlayStation headers
#include "PSX.h"

// USB Headers
#include "usbdrv.h"
#include "HIDDescriptor.h"
#include "USB.h"


/******************************************************************************
 * Defines and typedefs (enums, typedefs, constant macro defines, function macro defines)
 ******************************************************************************/

#define LED_PSX_ON()        (PORTD |=  _BV(PORTD5))
#define LED_PSX_OFF()       (PORTD &= ~_BV(PORTD5))
#define LED_USB_ON()        (PORTD |=  _BV(PORTD6))
#define LED_USB_OFF()       (PORTD &= ~_BV(PORTD6))
#define LED_PAD_ON()        (PORTD |=  _BV(PORTD7))
#define LED_PAD_OFF()       (PORTD &= ~_BV(PORTD7))


/******************************************************************************
 * External data déclarations (extern)
 ******************************************************************************/

/******************************************************************************
 * Prototypes and descriptions
 ******************************************************************************/

/**
 * @brief       Fonction de désactivation du chien de garde
 * @details     Cette fonction permet de désactiver le chien de garde
 */
static void disable_watchdog(void);

/**
 * @brief       Fonction d'initialisation générale du microcontroleur
 * @details     Cette fonction permet l'initialisation des différents éléments
 *              du microcontroller telles que ces entrées / sorties ou la
 *              gestion de l'alimentation
 */
static void init(void);

/**
 * @brief       Fonction de mise à jour du prochain report à transmetrte
 * @details     Fonction appelée le plus souvent possible
 */
static void updateHIDReport(HIDReport *report);

/**
 * @brief       Fonction de mise à jour des LEDs actives
 * @details     Cette fonction active la ou les leds correspondant
 *              aux touches appuyées sur le tapis.
 *              La correspondance se fait en fonction d'un tapis pour PS2
 */
static void updateLEDs(void);

/**
 * @brief       Boucle de gestion du mode USB
 * @details     Cette fonction permet de gérer le PAD en mode USB
 */
static void usb_mode(void);

/**
 * @brief       Boucle de gestion du mode Playstation
 * @details     Cette fonction permet de gérer le PAD en mode Playstation
 */
static void playstation_mode(void);

/**
 * @brief       Point d'entrée principal du programme
 * @details     Fonction appelée au démarrage du microcontroleur
 */
int main(void);


/******************************************************************************
 * Local variables
 ******************************************************************************/

// Report USB
HIDReport currentReport;


/******************************************************************************
 * Implements
 ******************************************************************************/

static void updateHIDReport(HIDReport *report)
{
	report->buttons = 0
		| (bit_is_clear(PINA, PINA0) ? HID_MASK_BTN_01 : 0)
		| (bit_is_clear(PINA, PINA1) ? HID_MASK_BTN_02 : 0)
		| (bit_is_clear(PINA, PINA2) ? HID_MASK_BTN_03 : 0)
		| (bit_is_clear(PINA, PINA3) ? HID_MASK_BTN_04 : 0)
		| (bit_is_clear(PINA, PINA4) ? HID_MASK_BTN_05 : 0)
		| (bit_is_clear(PINA, PINA5) ? HID_MASK_BTN_06 : 0)
		| (bit_is_clear(PINA, PINA6) ? HID_MASK_BTN_07 : 0)
		| (bit_is_clear(PINA, PINA7) ? HID_MASK_BTN_08 : 0)
		| (bit_is_clear(PINC, PINC0) ? HID_MASK_BTN_09 : 0)
		| (bit_is_clear(PINC, PINC1) ? HID_MASK_BTN_10 : 0)
		| (bit_is_clear(PINC, PINC2) ? HID_MASK_BTN_11 : 0)
		| (bit_is_clear(PINC, PINA3) ? HID_MASK_BTN_12 : 0)
		| (bit_is_clear(PINC, PINA4) ? HID_MASK_BTN_13 : 0)
		| (bit_is_clear(PINC, PINA5) ? HID_MASK_BTN_14 : 0)
		| (bit_is_clear(PINC, PINA6) ? HID_MASK_BTN_15 : 0)
		| (bit_is_clear(PINC, PINA7) ? HID_MASK_BTN_16 : 0)
	;
}

static void updateLEDs(void) {
    // Map PS2 pad to led
    uint8_t leds = 0x00
        | (bit_is_clear(PINC, PINC7) ? _BV(7) : 0) // LED-BR (SQUARE B3   - PC 7)
        | (bit_is_clear(PINA, PINA6) ? _BV(6) : 0) // LED-B  (DOWN        - PA 6)
        | (bit_is_clear(PINC, PINC4) ? _BV(5) : 0) // LED-BL (TRIANGLE B4 - PC 4)
        | (bit_is_clear(PINA, PINA5) ? _BV(4) : 0) // LED-R  (RIGHT       - PA 5)
        | (bit_is_clear(PINA, PINA7) ? _BV(3) : 0) // LED-L  (LEFT        - PA 7)
        | (bit_is_clear(PINC, PINC5) ? _BV(2) : 0) // LED-UR (CIRCLE B2   - PC 5)
        | (bit_is_clear(PINA, PINA4) ? _BV(1) : 0) // LED-U  (UP          - PA 4)
        | (bit_is_clear(PINC, PINC6) ? _BV(0) : 0) // LED-UL (CROSS B1    - PC 6)
    ;
    HC595_write(leds);

    if ((uint8_t)~PINA || (uint8_t)~PINC) {
        LED_PAD_ON();
    } else {
        LED_PAD_OFF();
    }
}

static void disable_watchdog(void) {
    wdt_reset();
    // Clear WDRF in MCUSR
    MCUSR &= ~_BV(WDRF);
    // Write logical one to WDCE and WDE
    // Keep old prescaler setting to prevent unintentional time-out
    WDTCSR |= _BV(WDCE) | _BV(WDE);
    // Turn off WDT
    WDTCSR = 0x00;
}

static void init(void) {
    cli();

    disable_watchdog();

    // Par défaut, on coupe tout
    power_adc_disable();
    power_spi_disable();
    power_timer0_disable();
    power_timer1_disable();
    power_timer2_disable();
    power_twi_disable();
    power_usart0_disable();
    power_usart1_disable();

    // 1 output; 0 input
    DDRA = 0b00000000;
    DDRB = 0b00000000;
    DDRC = 0b00000000;
    DDRD = 0b11100000;  // LEDs output

    // pull-up for pads (set to 1)
    PORTA = 0b11111111;
    PORTB = 0b00000000;
    PORTC = 0b11111111;
    PORTD = 0b00000000;

    USART_Init();

    stdout = &uart_output;
    stdin  = &uart_input;

    HC595_init();

    sei();
}

// For DEBUG purposes
#define MAX_SAMPLES     400
volatile uint8_t sampled_seq[MAX_SAMPLES];
volatile uint8_t sent_seq[MAX_SAMPLES];
volatile uint16_t sample_num=0;

static void playstation_mode() {
    printf("Playstation Mode (3.3V)\n");

    LED_PSX_ON();
    LED_USB_OFF();

    PSX_init();

    // NOTES :
    // La console interroge la manette toutes les 20ms.
    // PSX_PIN_RXD (MISO) et PSX_PIN_DSR (ACK) sont en collecteur ouvert (open drain)
    // Durée d'un ack : 2us
    // Délai entre dernier bit lu et un ack : 10us
    // Le dernrier bit n'a jamais de ACK
    // si _PSX_PIN_DTR_ high, alors la communication est terminée

    // TODO : Mettre un timer pour la sécurrité. Si timeout : Fin de la com
    // TODO : Mettre un watchdog

    while(1) {

        // Wait for _PSX_PIN_DTR_
        loop_until_bit_is_clear(PSX_PIN, PSX_PIN_DTR);

        // NOTES :
        // - Inspiration : https://gist.github.com/scanlime/5042071
        // - Pour DDR, nous n'avons pas besoin de coder tout le protocol
        //   d'un dualshock 2.
        // - Jeux testés :
        //     + DDR Supernova (JAP)
        //     + DDR Supernova 2 (US)
        //     + DDR MAX 2 7ème mix (JAP)
        //     + DDR MAX 6ème mix (JAP)
        //     + DDR MAX (US)
        //     + DDR MAX 2 (US)
        //     + DDR Extreme 2 (US)
        //     + DDR X (FR)

        uint8_t value = PSX_read_byte(0xFF);
        sent_seq[sample_num] = 0xFF;
        sampled_seq[sample_num++] = value;

        if (value == 0x01 && bit_is_clear(PSX_PIN, PSX_PIN_DTR)) {
        
            PSX_ack();
            value = PSX_read_byte(0x41);
            sent_seq[sample_num] = 0x41;
            sampled_seq[sample_num++] = value;

            if (value == 0x42 && bit_is_clear(PSX_PIN, PSX_PIN_DTR)) {
                PSX_ack();
                
                value = PSX_read_byte(0x5A);
                sent_seq[sample_num] = 0x5A;
                sampled_seq[sample_num++] = value;
                if (bit_is_clear(PSX_PIN, PSX_PIN_DTR)) {
                    PSX_ack();
                    
                    value = PSX_read_byte(PINA);
                    sent_seq[sample_num] = PINA;
                    sampled_seq[sample_num++] = value;
                    if (bit_is_clear(PSX_PIN, PSX_PIN_DTR)) {
                        PSX_ack();
                        
                        value = PSX_read_byte(PINC);
                        sent_seq[sample_num] = PINC;
                        sampled_seq[sample_num++] = value;
                    }
                }
            }
        }

        PSX_release_line();

        // Wait end of _SS_
        loop_until_bit_is_set(PSX_PIN, PSX_PIN_DTR);

        //
        // On a approximativement 19ms pour faire ce que l'on veut ici
        //

        // On met à jour les LED
        updateLEDs();

        // DEBUG : A voir si l'on garde ce bout de code...
        printf("TX  -> ");
        for (uint8_t i = 0; i < sample_num; i++) {
            printf("0x%02X ", sampled_seq[i]);
        }
        if (sample_num < 4) {
            printf("(fail)");
        }
        printf("\n");
        
        printf("  RX > ");
        for (uint8_t i = 0; i < sample_num; i++) {
            printf("0x%02X ", sent_seq[i]);
        }
        printf("\n\n");

        sample_num = 0;
    }
}

static void usb_mode() {
    printf("USB Mode (5V)\n");

    LED_PSX_OFF();
    LED_USB_ON();

    // Cf. https://codeandlife.com/2012/01/29/avr-attiny-usb-tutorial-part-3/
    
    // TODO : Mettre un watchdog

    usbInit();

    usbDeviceDisconnect(); // enforce re-enumeration
    _delay_ms(500);
    usbDeviceConnect();

    while (1) {
        usbPoll();
        updateHIDReport(&currentReport);
        updateLEDs();

        if (usbInterruptIsReady()) {
            usbSetInterrupt((uchar *)&currentReport, sizeof(currentReport));

            while (!usbInterruptIsReady()) {
                usbPoll();
            }
        }
    }
}

int main(void) {

    init();

    // On éteint les leds
    // NOTE : Il restera tout de même un flash à l'allumage
    HC595_write(0x00);
    LED_PSX_OFF();
    LED_USB_OFF();
    LED_PAD_OFF();

    printf("\n");
    printf("-------- Démarrage ------------\n");
    printf("\n");

    if (bit_is_clear(PINB, PINB2)) {
        usb_mode();
    } else {
        playstation_mode();
    }

    return 0;
}

/******************************************************************************
 * Interruptions
 ******************************************************************************/

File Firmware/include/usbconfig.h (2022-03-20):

/* Name: usbconfig.h
 * Project: V-USB, virtual USB port for Atmel's(r) AVR(r) microcontrollers
 * Author: Christian Starkjohann
 * Creation Date: 2005-04-01
 * Tabsize: 4
 * Copyright: (c) 2005 by OBJECTIVE DEVELOPMENT Software GmbH
 * License: GNU GPL v2 (see License.txt), GNU GPL v3 or proprietary (CommercialLicense.txt)
 */

#ifndef __usbconfig_h_included__
#define __usbconfig_h_included__

/*
General Description:
This file is an example configuration (with inline documentation) for the USB
driver. It configures V-USB for USB D+ connected to Port D bit 2 (which is
also hardware interrupt 0 on many devices) and USB D- to Port D bit 4. You may
wire the lines to any other port, as long as D+ is also wired to INT0 (or any
other hardware interrupt, as long as it is the highest level interrupt, see
section at the end of this file).
+ To create your own usbconfig.h file, copy this file to your project's
+ firmware source directory) and rename it to "usbconfig.h".
+ Then edit it accordingly.
*/

/* ---------------------------- Hardware Config ---------------------------- */

#define USB_CFG_IOPORTNAME      B
/* This is the port where the USB bus is connected. When you configure it to
 * "B", the registers PORTB, PINB and DDRB will be used.
 */
#define USB_CFG_DMINUS_BIT      0
/* This is the bit number in USB_CFG_IOPORT where the USB D- line is connected.
 * This may be any bit in the port.
 */
#define USB_CFG_DPLUS_BIT       1
/* This is the bit number in USB_CFG_IOPORT where the USB D+ line is connected.
 * This may be any bit in the port. Please note that D+ must also be connected
 * to interrupt pin INT0! [You can also use other interrupts, see section
 * "Optional MCU Description" below, or you can connect D- to the interrupt, as
 * it is required if you use the USB_COUNT_SOF feature. If you use D- for the
 * interrupt, the USB interrupt will also be triggered at Start-Of-Frame
 * markers every millisecond.]
 */
#define USB_CFG_CLOCK_KHZ       (F_CPU/1000)
/* Clock rate of the AVR in kHz. Legal values are 12000, 12800, 15000, 16000,
 * 16500, 18000 and 20000. The 12.8 MHz and 16.5 MHz versions of the code
 * require no crystal, they tolerate +/- 1% deviation from the nominal
 * frequency. All other rates require a precision of 2000 ppm and thus a
 * crystal!
 * Since F_CPU should be defined to your actual clock rate anyway, you should
 * not need to modify this setting.
 */
#define USB_CFG_CHECK_CRC       0
/* Define this to 1 if you want that the driver checks integrity of incoming
 * data packets (CRC checks). CRC checks cost quite a bit of code size and are
 * currently only available for 18 MHz crystal clock. You must choose
 * USB_CFG_CLOCK_KHZ = 18000 if you enable this option.
 */

/* ----------------------- Optional Hardware Config ------------------------ */

/* #define USB_CFG_PULLUP_IOPORTNAME   D */
/* If you connect the 1.5k pullup resistor from D- to a port pin instead of
 * V+, you can connect and disconnect the device from firmware by calling
 * the macros usbDeviceConnect() and usbDeviceDisconnect() (see usbdrv.h).
 * This constant defines the port on which the pullup resistor is connected.
 */
/* #define USB_CFG_PULLUP_BIT          4 */
/* This constant defines the bit number in USB_CFG_PULLUP_IOPORT (defined
 * above) where the 1.5k pullup resistor is connected. See description
 * above for details.
 */

/* --------------------------- Functional Range ---------------------------- */
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

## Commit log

2022-03-12 Version initiale avec USB opérationnel
    [DDRPadDriver.kicad_pcb, DDRPadDriver.sch, LEDs.sch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]
2022-03-12 Add hc595 support
    [DDRPadDriver.sch, LEDs.sch]
2022-03-13 Add schematics TODOs
    [DDRPadDriver.sch, LEDs.sch, Pads.sch]
2022-03-13 refactoring HC595 + LED / PAD mapping
    [LEDs.sch, Pads.sch]
2022-03-14 Revue des pads (ajustement Zener)
    [DDRPadDriver.sch, Pads.sch]
2022-03-19 Communication avec a PS2 OK
    [DDRPadDriver.sch]
2022-03-19 Un peu de ménage dans le code
    [DDRPadDriver.sch]
2022-03-19 Finalisation Firmware, renommage des pins pour la PSX
    [DDRPadDriver.sch, PS2Connector.sch]
2022-03-19 Toute la schematic est testé OK
    [DDRPadDriver.sch]
2022-03-20 Ajout de ma licence V-USB
    [PS2Connector.sch]
2022-04-24 Add freeCAD design for child DDR Pad
    [LittleDancePad.FCStd]
2022-04-24 Add CAD pad contacts
    [LittleDancePad.FCStd]
2022-04-24 Add CAD polycarbonate pads
    [LittleDancePad.FCStd]
2022-04-24 Add CAD CNC cut for inner pad
    [LittleDancePad.FCStd]
2022-04-24 Add schematic numerotation
    [DDRPadDriver.sch, LEDs.sch, PS2Connector.sch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]
2022-04-28 Ajout des empruntes des composants
    [DDRPadDriver.kicad_pcb, DDRPadDriver.sch, LEDs.sch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]
2022-04-30 Add 3D models and footprints
    [DDRPadDriver.kicad_pcb, DDRPadDriver.sch, LEDs.sch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]
2022-05-07 Partial routing PCB
    [DDRPadDriver.kicad_pcb, LEDs.sch]
2022-05-11 Finalisation PCB
    [DDRPadDriver.kicad_pcb]
2022-05-15 Add CAD Box pat
    [LittleDancePad.FCStd]
2022-05-17 Add START and SELECT buttons and START Job for CNC
    [LittleDancePad.FCStd]
2022-05-18 CAD : Add START and SELECT Job
    [LittleDancePad.FCStd]
2022-05-26 Add START and SELECT Job
    [LittleDancePad.FCStd]
2022-05-27 CAD : Initialize Power Supply
    [Power_Supply.FCStd]
2022-05-27 CAD : Power Supply - Add IEC plug
    [Power_Supply.FCStd]
2022-05-27 CAD : Power Supply - Add left side
    [Power_Supply.FCStd]
2022-05-27 CAD : Power Supply - Add front side
    [Power_Supply.FCStd]
2022-05-27 CAD : Power Supply - Add front aluminium profile
    [Power_Supply.FCStd]
2022-05-27 CAD : Power Supply - Add screen printing on aluminium profile
    [Power_Supply.FCStd]
2022-05-28 CAD : Add milling wood cuts
    [Power_Supply.FCStd]
2022-05-29 CAD : Add Aluminium profile job for power supply and test screen printing
    [Power_Supply.FCStd]
2022-05-29 CAD : Add reenforcements to LittleDancePad
    [LittleDancePad.FCStd]
2022-06-06 CAD : Finalize panels for Children pad and power supply
    [LittleDancePad.FCStd, Power_Supply.FCStd]
2022-06-11 CAD : Initialize adult DDR pad
    [DancePad.FCStd]
2022-06-26 CAD : Add supports
    [DancePad.FCStd]
2026-04-19 Add documentation for DualShock 2 frame and include related images
2026-04-19 Cleanup CAD directory and upgrade to FreeCAD 1.1.1
    [DancePad.FCStd, LittleDancePad.FCStd, Power_Supply.FCStd]
2026-04-19 Stable version
    [DancePad.FCStd]
